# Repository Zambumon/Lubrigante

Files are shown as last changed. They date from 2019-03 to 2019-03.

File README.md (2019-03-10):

# Lubrigante

_A TGR Alice Acrylic Case Revision By Zambumon_

### CHECK THE ISSUES TAB BEFORE MAKING THIS CASE

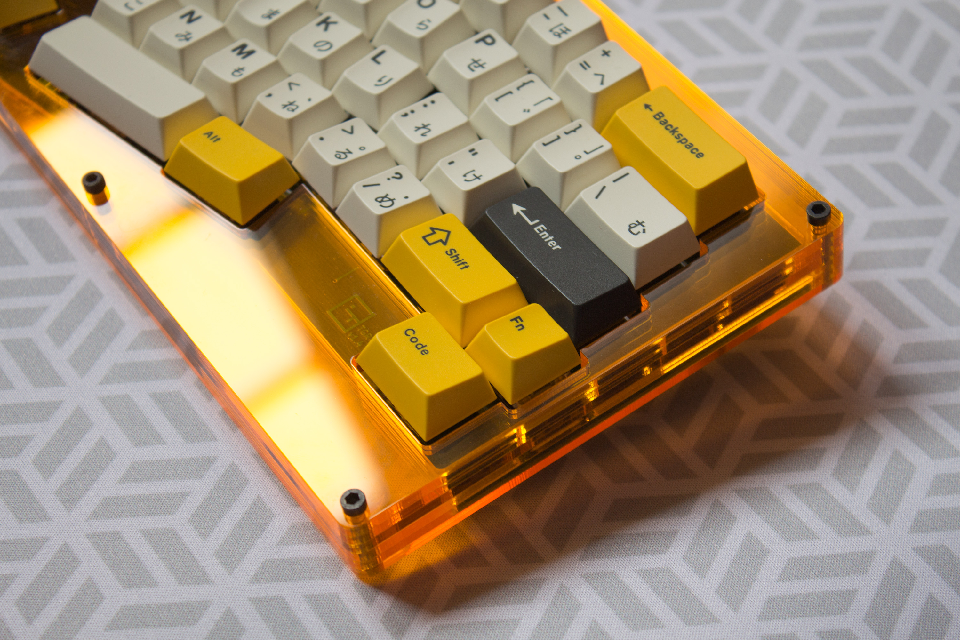
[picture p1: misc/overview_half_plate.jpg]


The aim of this project is to revisit the TGR Alice acrylic case (designed by Yuktsi), and host a guide with some basic resources so you can make your own.

You can find Yuktsi's original case files [here](https://geekhack.org/index.php?topic=95054.msg2661499#msg2661499).

### Differences between Lubrigante and Alice

- 4mm corners and a smaller footprint
- Top piece opening has now round corners instead of sharp ones
- Compatible with screw-in stabs.
- Fixed layout both for half-plate and full-plate.

# Disclaimer

**THIS IS A WORK IN PROGRESS PROJECT. USE THE FILES AT YOUR OWN RISK**

## Available layouts:

- **MAN OF LAYOUTS**: fixed layout. Stepped caps lock, 2.00U space bar next to a 1.25U modifier, standard backspace.
  - **Half plate**
  - ~~**Full plate**~~ _reworking_

---

## Making the case

Wherever you use the files, make sure to **set the scale to millimetres**. **The keyboard should be 348.8mm wide.**

The case is made with multiple layers of acrylic that are stacked on top of each other and held together with 8 M3 screws. Each file has 5 distinct pieces:
- **Piece A - Top opening**: this is the top piece of the of the case, the one with two openings. This piece is placed on top of the plate.
- **Piece B - Plate**: used to hold the switches, it is the one with switch and stab holes. On the left side lower corner it has a slot for the LEDs.
- **Piece C - Upper USB**: this piece is placed right under the plate and it is necessary for 3mm or lower plates. With a 5mm plates, you won't need it.
- **Piece D - Lower USB***: meant to be placed right on top of the bottom piece, the only difference with **Piece C** is the lack of an exit for the USB port.
- **Piece E - Bottom piece**: the one that closes the case. It has 3 M4 holes so you can install either 3 cone feet.

### Layer thicknesses: what are your alternatives?

- **3mm pieces**: probably the most versatile solution, as there are lots of acrylic finishes and it is the one I used while prototyping. It consists on **6 layers** of 3mm acrylic: 2x Piece A, 1x Piece B, 1x Piece C, 1x Piece D, and 1x Piece E.
- **5mm pieces**: this might look in the beginning as a more cost effective solution, but that might not be the case. The shop will probably use a bigger kerf to make the pieces, and that would be problematic for both most of them, specially the plate. If you decide to go with this route, there are two possibilities:
  - 1x Piece A, 1x Piece B, 1x Piece D, 1x Piece E.
  - 1x Piece A, 1x Piece C, 1x Piece D, 1x Piece E + a non-acrylic 1.5mm Piece B (either aluminum, brass, copper, carbon fiber, etc.).
- **The TGR way**: The original case used 3 different acrylic thicknesses: an 8mm Piece A, 5mm Piece B, 5mm Piece D, and 3mm Piece E. It had 8 countersunk M3 holes: 8 on Piece A, and two M4 countersunk on the Piece E. Additionally, its Piece E had 8 of its screw holes tapped.
- **Mix of 3mm and 5mm layers**: one possibility could be 1x 3mm Piece A, 1x 5mm Piece A, 1x 3mm Piece B, 1x 5mm Piece C, 1x 3mm Piece D, 1x 3mm Piece E.

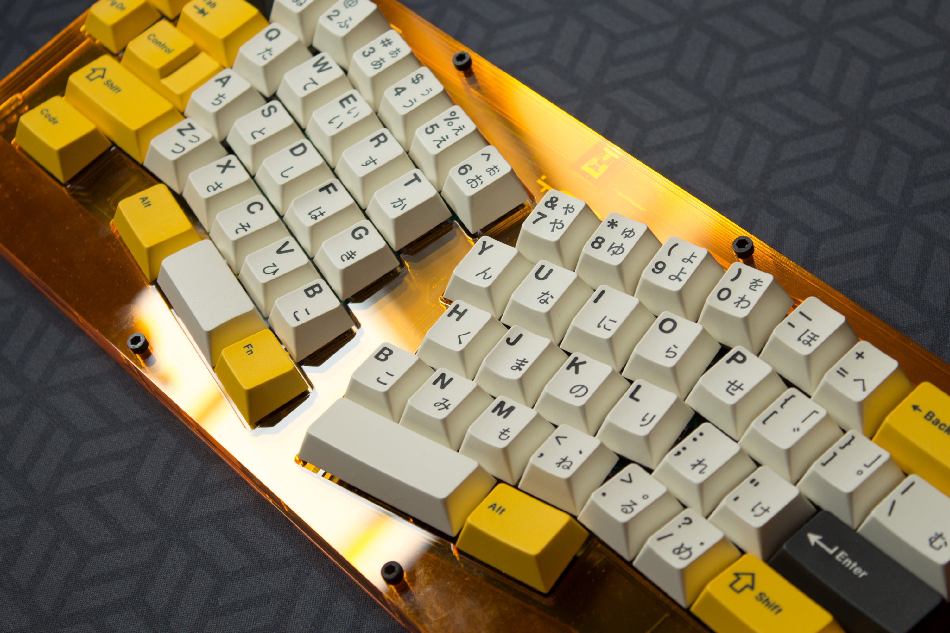
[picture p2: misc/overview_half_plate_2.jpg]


###  Ordering the acrylic pieces

There are a handful of ways of getting the acrylic pieces done:
- Contacting a local maker spaces or a laser cutting shop.
- Ordering online:
  - [Ponoko](https://www.ponoko.com) (NA)
  - [Formulor](https://www.formulor.de) (EU) I have used their service for the prototype. Shipping will be expensive as they have to use a large sheet of acrylic, so ordering multiple cases is recommended. The case will end up costing around 75 EUR + shipping.

### Other components

- PCB: you can use the original TGR Alice PCB or the one [Maarten Dekkers](https://github.com/Maartenwut) has designed and that will be available for purchase soon.
- [CNCd aluminum cone feet](http://lmgtfy.com/?q=cnc+aluminum+cone+feet). These will most likely come with M4 screws.
- Bumpons: I recommend using some `SJ5302 3M`, as these are very similar to the ones used by the CNCd cone feet.
- Screws:
  - 8x M3 20mm screws. The original acrylic TGR Alice used flat head nylon screws. I've used some hex socket screws. If you plan to use some nuts to hold the screws, you might need to use longer screws.

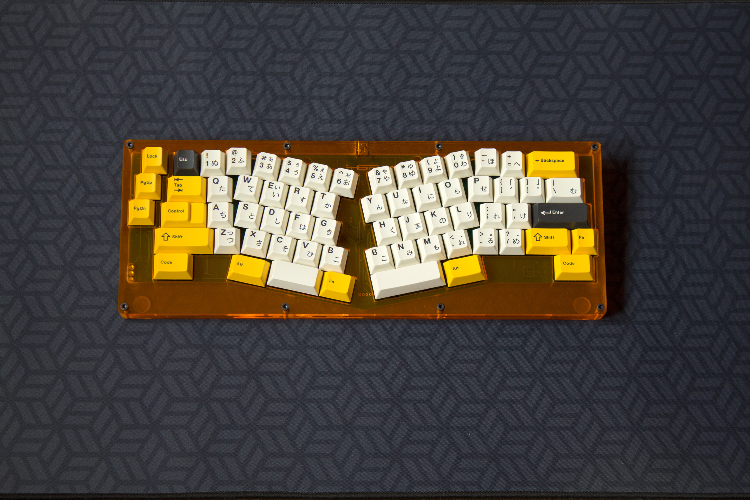
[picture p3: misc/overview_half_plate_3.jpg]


---

## License

This repository is under the [GNU GPL V3 license](./LICENSE). If you plan to sell these cases, make sure to read it.

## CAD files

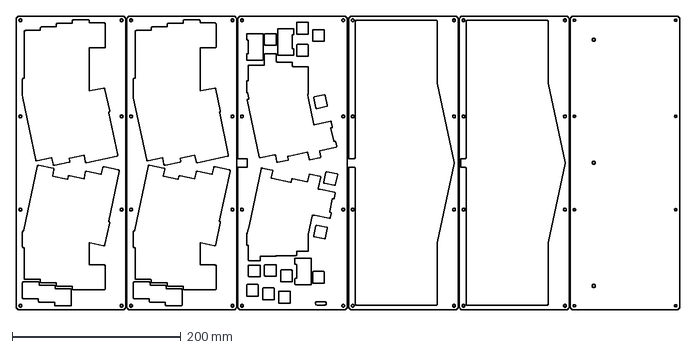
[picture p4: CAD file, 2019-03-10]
case_layouts/man_of_layouts/man_of_layouts_half_plate_3mm.dxf
787.8 x 348.8 mm

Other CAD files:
misc/tgr/alice_case_acrylic.DWG

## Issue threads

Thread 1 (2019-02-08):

Build a prototype

Zambumon, 2019-02-08:

Zambumon, 2019-02-24:
Ordered a 4 layer 5mm half plate from sculpteo.

adbX, 2019-03-05:
I have a `1/2 inch, 2 x 1/4 inch and 1/8 inch (12.7, 6.35 and 3.175 mm)` acrylic plates on hand and also have a laser cutting machine ready to go. Other than the screw lengths, would there be any issues?

Zambumon, 2019-03-06:
I've received the case. And I'm currently writing a short document with all the tweaks needed.

DanielGGordon, 2019-03-08:
@Zambumon I'm interested in producing at least 25x of these now that a PCB GB is open.

Zambumon, 2019-03-08:
@DanielGGordon this issue hasn't been closed. The case need some small tweaks and that PCB you are talking about isn't Maarten's. I strongly suggest you to hold your horses.

If you decide to sell them at your store, remember to follow the license on this repository.

airyimbin, 2019-03-08:
Wait if that preorder for the PCB isn't the one designed by Maarten, then what PCB is it?
I'm kind of confused since the GB link doesn't work.

Maartenwut, 2019-03-08:
> Wait if that preorder for the PCB isn't the one designed by Maarten, then what PCB is it?
> I'm kind of confused since the GB link doesn't work.

I don't know who will design this one, but it certainly isn't me. I quit the project. The GB link doesn't work because the moderators at geekhack have to approve every GB thread and they have not done that yet.

airyimbin, 2019-03-08:
So the picture he posted of the PCB was just your initial prototype?
At the end of the day as long it works I guess I'm ok with it.

Maartenwut, 2019-03-08:
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

The picture of the PCB with the routing is my finished design. Because I quit the project he is not allowed to use it anymore.

airyimbin, 2019-03-09:
Thanks for clarifying.

Zambumon, 2019-03-09:
Known issues with the prototype case:
- Switch holes should be a little bit tighter due to kerf. Reducing them could be an option. I bypassed this problem by placing some electrical tape aound the switch and they holds the switch down perfectly.
- Cone feet screw holes should be M4, not M3. For the prototype case, I just end up superglueing them.
- Due to the nature of acrylic, some people might want to add 3rd cone feet right in the middle to avoid the flex.
- Screw holes could be slightly thighter if we want to use the bottom piece to screw them. I just used some masking tape around each of the screws and there was no need for anything else.

The case doesn't present any major issues and it is compatible with the original PCB.

wamsleymj, 2019-03-09:
I would love to help contribute, please let me know how I can assist.

Couple of things in the read me that I think could use clarification.

When importing the files, make sure to set the scale to millimetres.
Are you speaking about importing the .dxf file into an AutoCAD like program or a fabrication website?

Ideally you'd want to use 20+ screws and some nuts.
So instead of 8 screws, there should be 20 around the case? Can the case handle that? Are you going to add the holes to the files, or should we manipulate them to add extra? It looks like the case can only take more screw holes on the top and bottom edges.

I appreciate all the hard work. Really excited about this project.

Zambumon, 2019-03-10:
> When importing the files, make sure to set the scale to millimetres.
> Are you speaking about importing the .dxf file into an AutoCAD like program or a fabrication website?

Both. Whenever you get asked about the scale, make sure you are using milimiters and double check it.

> Ideally you'd want to use 20+ screws and some nuts.
> So instead of 8 screws, there should be 20 around the case? Can the case handle that? Are you going to add the holes to the files, or should we manipulate them to add extra? It looks like the case can only take more screw holes on the top and bottom edges.

Bad phrasing on my side, it should say "20mm or more"

Zambumon, 2019-03-10:
Prototype built, files and readme updated.

raphaelfaria, 2019-03-12:
@Zambumon would the kerf (the loose switches issue) be a problem if I go the 1.5mm metal plate route? Probably not, right?

Zambumon, 2019-03-12:
@raphaelfaria I don't think so.

Closed 2019-03-10.

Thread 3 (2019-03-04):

Acrylic thicknesses & tolerance

gwerbin, 2019-03-04:
In the USA I think these are the most common acrylic thicknesses you will find (in mm):

- 1.5
- 2.5
- 3
- 4.5
- 6
- 9

Since those are somewhat misaligned with the numbers recommended by Yuktsi it might be useful to have a sense of the alternatives available.

In addition, apparently due to manufacturing tolerance "5mm" acrylic can end up being too thick for switches to sit correctly. So 4.5mm is typically what I have been told to use in the past for plates anyway.

I imagine you can get away with reducing both 5mm layers to 4.5mm and still have the PCB clear the bottom. Then you can do the top piece as two layers (4.5+3) or just leave it as a "mid height" bezel. But it would be good to have your thoughts, maybe once you've received your prototype.

Zambumon, 2019-03-04:
I'm currently testing 3mm with formulor. 3mm is easier to find and more inexpensive, it shouldn't crack the plate when installing the switches, and you can fit a 6 layer 3mm case within the constrains provided by Formulor (and probably Ponoko).

I'll post the results of my prototyping adventure at #1

Closed 2019-03-06.

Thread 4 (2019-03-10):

Full plate files

Zambumon, 2019-03-10:
Remake the DXF for the full plate version.

deepPhong, 2019-04-08:
I have zero experience designing plates, but wouldn't it be alright to use the file from [here](https://geekhack.org/index.php?topic=99160.0) with edges compatible with the Lubrigante?

saucybulgogi, 2019-06-11:
what exactly is wrong with the full plate files if you don't mind me asking? are the files in the 'The Man' alpha release not suitable for laser cutting?  just wondering as i want to handwire one of these with a full plate.

pookie69, 2019-10-10:
what is the problem with the full plate files

kurlymk, 2020-08-03:
when will this remake be completed?

Zambumon, 2020-08-07:
The original TGR files were full plate and are available here: https://github.com/Zambumon/Lubrigante/tree/master/misc/tgr

qihenry, 2021-11-21:
Is there any issue with that full plate?

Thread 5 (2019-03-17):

Ponoko error - stroke colours

rwarr, 2019-03-17:
I was trying the dxf file for the half plate on Ponoko where it gave out an error regarding about the stroke colour.

> There appears to be a problem with your design file: The stroke colors in your .dxf file aren’t quite right. Cutting strokes need to be RGB (0,0,255) blue. Vector engraving strokes need to be RGB (255,0,0) red.

Zambumon, 2019-03-17:
Open the file with inkscape or illustrator and change the colors.

rwarr, 2019-03-17:
Also, seems like ponoko is complaining about stray anchor points.

Maartenwut, 2019-03-17:
Zambumon is providing the designs, it's up to you to make them fit the manufacturer's specifications.

joehenriod, 2019-03-27:
@rwarr Did you get your files working? I'm editing some for Ponoko in Illustrator now if you want them posted.

addcninblue, 2019-10-25:
@joehenriod hey! did you manage to get working files? I'd love to print my own. Also, how much was the total cost?

Closed 2019-03-17.

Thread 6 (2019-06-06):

Not enough room for split backspace

deepPhong, 2019-06-06:
I don't know if it's on purpose or not, but the cutout for backspace is not large enough to fit two switches for split backspace, I had to file mine.

Zambumon, 2019-06-06:
From the README.md:

Available layouts:

MAN OF LAYOUTS:

- fixed layout. Stepped caps lock, 2.00U space bar next to a 1.25U modifier, standard backspace.

Closed 2019-06-06.

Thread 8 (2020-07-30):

Plate B

sekh0n, 2020-07-30:
Im guessing when you added stabilizer support for the backspace; you erroneously messed up the dimensions of the Plate-B.dxf file.

Zambumon, 2020-07-31:
I've replaced all the DXFs with SVGs as they are giving too many issues when importing/exporting from Inkscape.

Closed 2020-07-31.

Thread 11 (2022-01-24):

SVG files only show half of the plate

ek-db, 2022-01-24:
Is this just me or are the SVG files not the full plate layout and only showing around 60% of it?

MaxwellVale, 2022-01-29:
I see the same thing I'm pretty sure. Don't really know why though...

kevinr, 2023-03-11:
If you open the SVG files in an SVG editor like Inkscape, rather than in the Github viewer, the full plate outlines are there, but the document is configured with the ~60% width you see.  Most laser shops would copy the outlines on to a document configured to the bed size of their machine anyway for cutting, so the document size of the source files doesn't make too much difference really, and absent any design issues the full layouts are there and ready to use.

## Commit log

2019-03-02 3mm man of layouts half plate variant.
    [man_of_layouts_half_plate_3mm.dxf]
2019-03-09 README update. Removal of old files.
    [man_of_layouts_full_plate.dxf, man_of_layouts_half_plate.dxf]
2019-03-10 Updated man of layouts 3mm case. Added a third cone feet. Increased the holes, now they are 4mm wide.
    I have decided not to touch the plate or screw holes. As for the plate,
    decreasing the size of the switch holes could be problematic in some
    cases. For the screw holes, it's somehow similar and you can always use
    a nut
    [man_of_layouts_half_plate_3mm.dxf]
2020-07-26 revise individual shapes for easier cutting
    [Plate1.dxf, Plate2.dxf, Plate3.dxf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]
2020-07-26 fix naming to better match instructions
    [Plate2.dxf, PlateA.dxf, PlateB.dxf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]
2020-07-27 Add stabilizers support for backspace
    [PlateB.dxf]
2020-07-31 Replaced DXF with SVG
    Inkscape has issues reading and saving to DXF. I've replaced the individual part files with SVGs.
    [PlateA.dxf, PlateB.dxf, PlateC.dxf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]
